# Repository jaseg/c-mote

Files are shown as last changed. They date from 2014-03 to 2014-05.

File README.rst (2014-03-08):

c-mote
======

Mote_ is hipster slang for small, low-power, long-lifetime sensor nodes. We want to build a sensor network consisting of about 40 motes at c-base and AfRA (both hackerspaces in Berlin). Traditionally, the term applies to wireless sensors, but since we already have enough rays bouncing around at both places we opted for less expensive, more reliable wired communication via RS-485_ instead.

Hardware
--------

We are planning the base board to be about 5*5cm. The heart of the system is an Atmel ATmega8_ microcontroller. Most of the components on the board will be surface-mounted, though we aim to not use anything smaller than 0805 packages so we can still solder it by hand. The board is supplied via 5V routed with the RS-485 bus.

All of the sensors are optional to allow greater flexibility.

Some of the unused microcontroller IOs are routed to a 2*5 pin male 2.54mm pin header which serves as a connector for daughter boards. The first planned daughter board is a frontend for diffuse IR telemetry.

Sensor auto-detection
~~~~~~~~~~~~~~~~~~~~~

The default firmware will include modules for all sensors. The available sensors will be probed on power-on. The following table summarizes the conditions under which each of the sensors will be considered absent.

==================  ==============================  ======================================================
Sensor              Considered absent, when...      Activate µC's internal pull-up for presence detection?
==================  ==============================  ======================================================
Analog temperature  U_in > 4.0V                     yes
Light               U_in > 4.0V                     yes
Oxygen              U_in > 4.0V                     yes
Sound               U_in > 4.0V                     yes
Methane             U_in > 4.0V                     yes
Barometer           Probing via I2C fails
Hygrometer          No response on bus
NRF24L01            Probing via SPI fails
Motion              See text below
==================  ==============================  ======================================================

The motion sensor's presence detection is a bit tricky. This sensor is considered absent when the input is a logical 0 and switches to a logical 1 after the µC's internal pull-up is activated. This procedure is using the fact that the AVR's internal pull-up is something below 50kΩ and the motion sensor's output impedance is something below 10kΩ. When the motion sensor is left unpopulated, a 200kΩ pull-down resistor is added instead.

Bus
---
Most likely we will end up using regular CAT5e or better ethernet cable since that stuff is cheap and will probably do the job. Contrary to what one might expect after having a glance on the standard, RS-485 (TIA-485-A) actually is kind of picky concerning bus topologies. We plan on routing a long chain, avoiding any branches, by using two of the ethernet cable's twisted pairs for both directions into dead ends if necessary.

Protocol
--------

The first iteration of the network will be based on cerebrum_, since basically everything we need is already implemented there. This network will consist of one dedicated, internet-connected bus master (some kind of linux system with an USB/RS-485 converter) running a cerebrum daemon collecting data and forwarding it to MQTT_ and Graphite_.

The medium-term goal is to get the next-gen cerebrum protocol to work which is completely distributed and directly compatible to 6LoWPAN_. At this point, it would be sensible to implement MQTT_ directly on the motes using contiki_ for its 6LoWPAN stack.

MAC address handling
~~~~~~~~~~~~~~~~~~~~
Cerebrum, and probably any successor to it, uses random 64-bit MAC adresses for auto-discovery. The current plan is to use a common firmware binary with sensor auto-detection on all nodes. Device-specific configuration, specifically device name, MAC and spatial coordinates should simply be stored in EEPROM. The chosen approach is to have all devices start with a build-specific, random MAC that is used until a proper, random MAC has been configured along with the device's name and coordinates. Thus, the devices can be added to the bus and configured one-by-one without requiring another compilation step.

.. _Mote:       https://en.wikipedia.org/wiki/Motes
.. _RS-485:     https://en.wikipedia.org/wiki/RS-485
.. _ATmega8:    http://www.atmel.com/Images/Atmel-2486-8-bit-AVR-microcontroller-ATmega8_L_summary.pdf
.. _cerebrum:   https://github.com/jaseg/cerebrum
.. _MQTT:       https://en.wikipedia.org/wiki/MQ_Telemetry_Transport
.. _Graphite:   https://github.com/graphite-project/graphite-web
.. _6LoWPAN:    https://en.wikipedia.org/wiki/6LoWPAN
.. _contiki:    http://www.contiki-os.org/

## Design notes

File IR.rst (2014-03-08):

IR Telemetry
============

The purpose of this board is to serve as an analog frontend for low-bitrate (≤1Mbps), short-range (≤5m) IR communication. The design consists of two identical halves which are supposed to cover on hemisphere each.

Transmission path
-----------------

Reception path
--------------
http://www.aliexpress.com/item/940nm-narrow-band-pass-filter-board-lens-filters-filter-diameter-8-0mm-night-vision-filter/569348422.html

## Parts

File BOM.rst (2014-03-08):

BOM
===

**Note:** In the following table, the brutto prices two conrad parts have been converted to USD for summation convenience.

==  ==============================================================  ==================================================  =========
#   What                                                            Sources                                             Price/ea.
==  ==============================================================  ==================================================  =========
1   RS485 driver SN75176BP                                          `Tayda <tayda1_>`__                                     0.39$
1   ATMega8 8-bit µC w/ nice peripheral selection and 5V operation  `Tayda <tayda2_>`__                                     1.89$
1   Crystal for good bus timing                                     `Tayda <tayda3_>`__                                     0.10$
1   Load caps for crystal oscillator, 22pF 0805 cer.                `Tayda <tayda4_>`__                                     0.01$
1   Buffer cap for entire circuit, 4.7µ electrolytic 2.54mm leads   `Tayda <tayda11_>`__                                    0.02$
1   4pin terminal for bus/VCC connection                            `Conrad <conrad1_>`__                                   0.73$
1   5pin terminal for contact connection (GND/VCC/IO1-3)            `Conrad <conrad2_>`__                                   0.91$
1   PCB <5*5cm                                                      `Seeedstudio <seeed1_>`__                               1.00$
1   LDO 3.3V SOT223 TS1117                                          `Reichelt <reich1_>`__ `Aliexpress <aliex16_>`__        0.06$
\   **Total**                                                                                                               5.05$
==  ==============================================================  ==================================================  =========

.. _tayda1:  http://www.taydaelectronics.com/ic-integrated-circuits/rs422-rs423-rs485/sn75176-sn75176bp-75176-buffers-line-drivers-ic.html
.. _tayda2:  http://www.taydaelectronics.com/ic-integrated-circuits/microcontrollers/atmel-atmega8-16au-tqfp-32-avr-8-bit-microcontroller-ic.html
.. _tayda3:  http://www.taydaelectronics.com/crystals-resonators-oscilliators/crystals/16-000-mhz-16-mhz-crystal-hc-49-s-low-profile.html
.. _tayda4:  http://www.taydaelectronics.com/capacitors/smd-ceramic-chip-capacitors/0805/22pf-50v-smd-ceramic-chip-capacitor.html
.. _tayda10: http://www.taydaelectronics.com/resistors/smd-chip-resistors/0805/50-x-smd-chip-resistors-10k-ohm-1-8w-1-0805.html
.. _tayda11: http://www.taydaelectronics.com/capacitors/electrolytic-capacitors/4-7uf-16v-105c-radial-electrolytic-capacitor-5x11mm.html
.. _conrad1: http://www.conrad.de/ce/de/product/567658/Loetbare-Schraubklemme-mit-Liftprinzip-AKZ692-V-Rastermass-254-mm-Polzahl-4-Gruen-50692040021E-Inhalt-1-St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
.. _conrad2: http://www.conrad.de/ce/de/product/567698/Loetbare-Schraubklemme-mit-Liftprinzip-AKZ692-V-Rastermass-254-mm-Polzahl-5-Gruen-50692050021E-Inhalt-1-St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
.. _seeed1:  http://www.seeedstudio.com/service/index.php?r=site/pcbService
.. _reich1:  https://secure.reichelt.de/TS-1117-BCW33/3/index.html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
.. _aliex16: http://www.aliexpress.com/item/Free-Shipping-100PCS-Original-AMS1117-3-3-AMS1117-3-3V-AMS1117-1117-3-3V-1A-Voltage/1149210196.html

Remember to also throw in a couple of **termination resistors** for the system in accordance to your cable's impedance (e.g. 100Ω for ethernet cable).

Indicator option 1: RGB LED
---------------------------

==  ==============================================================  ======================================  =========
#   What                                                            Sources                                 Price/ea.
==  ==============================================================  ======================================  =========
1   RGB LED as status indicator                                     `Tayda <tayda5_>`__                         0.27$
1   Cur. limit resistor for RGB LED, 0805, 150Ω (R)                 `Tayda <tayda12_>`__                        0.01$
2   Cur. limit resistor for RGB LED, 0805, 100Ω (G/B)               `Tayda <tayda13_>`__                        0.01$
\   **Total**                                                                                                   0.30$
==  ==============================================================  ======================================  =========

.. _tayda5:  http://www.taydaelectronics.com/leds/round-leds/5mm-leds/rgb-leds/rgb-led-5mm-common-cathode.html
.. _tayda12: http://www.taydaelectronics.com/resistors/smd-chip-resistors/0805/50-x-smd-chip-resistors-100-ohm-1-8w-1-0805.html 
.. _tayda13: http://www.taydaelectronics.com/resistors/smd-chip-resistors/0805/50-x-smd-chip-resistors-150-ohm-1-8w-1-0805.html

Indicator option 2: Red 8*8 LED dot matrix (32*32mm)
----------------------------------------------------

==  ==============================================================  ======================================  =========
#   What                                                            Sources                                 Price/ea.
==  ==============================================================  ======================================  =========
1   Red 8*8 32*32mm LED dot matrix                                  `Tayda <tayda14_>`__                        1.35$
1   7-ch NPN darlington array ULN2003APG                            `Tayda <tayda15_>`__                        0.28$
2   8bit shift register w/ output latches                           `Tayda <tayda16_>`__                        0.27$
1   NPN darlington transistor 2N5306                                `Tayda <tayda17_>`__                        0.14$
1   Transistor base resistor 0805 330K                              `Tayda <tayda18_>`__                        0.01$
8   LED current limit resistors 0805 100Ω                           `Tayda <tayda19_>`__                        0.01$
0   Alternative high current shift register                         `Digikey <digikey1_>`__                     1.51$
\   **Total**                                                                                                   2.40$
==  ==============================================================  ======================================  =========

.. _tayda14:  http://www.taydaelectronics.com/led-displays/dot-matrix/8x8-dot-matrix-led-display-red-3mm-common-cathode.html
.. _tayda15:  http://www.taydaelectronics.com/ic-integrated-circuits/transistor-arrays/uln2003apg-uln2003-array-7-npn-darlingtons-ic.html
.. _tayda16:  http://www.taydaelectronics.com/ic-integrated-circuits/74-series/74hc-series/74hc595-8-bit-shift-register-ic.html
.. _tayda17:  http://www.taydaelectronics.com/t-transistors/2n-series/2n5306-npn-darlington-transistor.html
.. _tayda18:  http://www.taydaelectronics.com/resistors/smd-chip-resistors/0805/50-x-smd-chip-resistors-330k-ohm-1-8w-1-0805.html
.. _tayda19:  http://www.taydaelectronics.com/resistors/smd-chip-resistors/0805/50-x-smd-chip-resistors-100-ohm-1-8w-1-0805.html
.. _digikey1: http://www.digikey.com/product-search/en?x=0&y=0&lang=en&site=us&KeyWords=TPIC6B595

Sensors
-------

======  ==============================================================  ==================================================  =========
#       What                                                            Sources                                             Price/ea.
======  ==============================================================  ==================================================  =========
1       Photoresistor                                                   `Tayda <tayda6_>`__                                     0.24$
1       Bootstrap resistor for photo resistor, 10k 0805                 `Tayda <tayda10_>`__                                    0.01$
0       Digital temperature sensor                                      `Tayda <tayda7_>`__                                     1.75$
0.5     Alternative analog temperature sensor LM335                     `Tayda <tayda20_>`__                                    0.81$
0.5     Alternative analog temperature sensor bias resistor                                                                     0.01$
1       PIR (motion sensor) module                                      `Aliexpress <aliex1_>`__ `(Proto) <aliex7_>`__          1.01$
0.3333  Optical particle sensor Sharp GP2Y1010AU0F w/ cable             `Aliexpress <aliex2_>`__ `(Proto) <aliex8_>`__          6.40$
0       Oxygen sensor Alphasense O2-A2 (1~2yr lifetime)                 `Aliexpress <aliex3_>`__                               51.84$
0.3333  Oxygen sensor Envitec OOA101-1 (compatible; 3yr lifetime)       `Aliexpress <aliex4_>`__ `(Proto) <aliex9_>`__          7.07$
0.3333  Passives for oxygen sensor                                                                                              0.05$
0.3333  3.5mm headphone plug for oxygen sensor                          `Tayda <tayda21_>`__                                    0.16$
0.5     Humidity sensor DHT22 (**replaces temp. sensor**)               `Aliexpress <aliex5_>`__ `(Proto) <aliex10_>`__         3.95$
1       Air pressure sensor BMP085                                      `Aliexpress <aliex6_>`__ `(Proto) <aliex11_>`__         2.19$
1       NRF24L01 (2.4GHz transceiver as used in r0kets)                 `Aliexpress <aliex12_>`__                               0.85$
0.3333  MQ214 Methane/Propane/Buthane sensor                            `Aliexpress <aliex13_>`__                               3.69$
0.3333  MQ214 load resistor 0805 43Ω                                    `Tayda <tayda22_>`__                                    0.01$
0       Piezo transducer                                                `Aliexpress <aliex14_>`__                               1.27$
0       3.5mm mono headphone jack for piezo transducer                                                                          0.20$
0       27mm piezo buzzer disc as force/vibration sensor                `Aliexpress <aliex15_>`__                               0.16$
\       **Total**                                                                                                              12.66$
======  ==============================================================  ==================================================  =========

.. _tayda6:  http://www.taydaelectronics.com/sensors-transducer/optical-sensor/photo-conductive-cell-resistor-ldr-650nm-radial-ke-10720.html 
.. _tayda7:  http://www.taydaelectronics.com/ic-integrated-circuits/temperature-sensors/ds18b20-1-wire-digital-temperature-sensor-ic-dallas.html
.. _tayda20: http://www.taydaelectronics.com/ic-integrated-circuits/temperature-sensors/lm335-precision-temperature-sensor-40c-to-100c-ic.html
.. _tayda21: http://www.taydaelectronics.com/3-5mm-stereo-plug.html
.. _tayda22: http://www.taydaelectronics.com/resistors/smd-chip-resistors/0805/50-x-smd-chip-resistors-43-ohm-1-8w-1-0805.html
.. _aliex1:  http://www.aliexpress.com/item/Free-Shipping-HC-SR501-Adjust-Infrared-IR-Pyroelectric-Infrared-PIR-module-Motion-Sensor-Detector-Module-We/1564561530.html
.. _aliex2:  http://www.aliexpress.com/item/2pcs-lot-GP2Y1010AU0F-100-NEW-SHARP-Optical-Dust-Sensor-GP2Y1010-free-shipping-add-cable/1670003835.html
.. _aliex3:  http://www.aliexpress.com/item/UK-Alphasense-alpha-O2-A2-oxygen-sensor-O2-A2/1613147048.html
.. _aliex4:  http://www.aliexpress.com/item/Envitec-oxygen-battery-oxygen-probe-ooa101-ooa101-1/1000408054.html
.. _aliex5:  http://www.aliexpress.com/item/10PCS-LOT-DHT22-AM2302-Digital-Temperature-and-Humidity-Sensor-DHT22-Free-shiping/1514942254.html
.. _aliex6:  http://www.aliexpress.com/item/Free-Shipping-10pcs-New-BMP085-Digital-Pressure-Sensor-module/1640086463.html
.. _aliex7:  http://www.aliexpress.com/item/NEW-PIR-Sensor-Human-Body-detecting-module-Pyroelectric-HC-SR501-For-Arduino-MCU-Freeshipping/875391018.html
.. _aliex8:  http://www.aliexpress.com/item/GP2Y1010AU0F-Compact-Optical-Dust-Sensor-Smoke-Particle-Sensor-With-Cable/1482509805.html
.. _aliex9:  http://www.aliexpress.com/item/Hot-4-Wire-Universal-Oxygen-Sensor-Lambda-Sensor-Free-Shipping-0258986501/1464938927.html
.. _aliex10: http://www.aliexpress.com/item/2pcs-DHT22-AM2302-SHT11-SHT15-Digital-Temperature-and-Humidity-Sensor-for-Ardunio-AVR-PIC-ARM-Raspberry/1628174960.html
.. _aliex11: http://www.aliexpress.com/item/5PCS-LOT-GY-65-BMP085-Atmospheric-Pressure-Altimeter-Module-Free-Shipping/1540253073.html
.. _aliex12: http://www.aliexpress.com/item/NRF24L01-wireless-data-transmission-module-2-4G-the-NRF24L01-20PCS-LOT-upgrade-version/603760995.html
.. _aliex13: http://www.aliexpress.com/item/Mq214-methane-sensor/1398325808.html
.. _aliex14: http://www.aliexpress.com/item/FREE-SHIPPING-30-Sensitive-New-Piezo-Under-saddle-Pickup-Transducer-Tuner-For-Ukulele/1402166893.html
.. _aliex15: http://www.aliexpress.com/item/20pcs-27mm-Thickness-0-33mm-Piezo-Disc-for-Buzzer-Pressure-Sensor-Speaker-DIY/1371976951.html

Loudness sensor subsystem
-------------------------
**Note:** The Op-Amp used in this subsystem is a dual type, so we need only one half of it. The other half is available for other uses.
Loudness sensor? → Microphone+amp+envelope detector

==  ==============================================================  ======================================  =========
#   What                                                            Sources                                 Price/ea.
==  ==============================================================  ======================================  =========
1   Electret microphone                                             `Tayda <tayda8_>`__                         0.25$
1   Dual Op-Amp                                                     `Tayda <tayda9_>`__                         0.11$
\*  Passives (**TODO**)                                                                                         0.05$
\   **Total**                                                                                                   0.41$
==  ==============================================================  ======================================  =========

.. _tayda8:  http://www.taydaelectronics.com/microphones/condenser-microphone-2-2k-ohm-1-5v.html
.. _tayda9:  http://www.taydaelectronics.com/ic-integrated-circuits/audio-amplifier-instrumentation-op-amp/tjm4558-dual-operational-amplifier-wide-band-soic-8-tjm4558cdt.html

Cabling
-------
We will use regular shielded ethernet cable. We will need a bunch of `splice boxes`_ to wire up cables going into dead ends.

.. _`splice boxes`: http://www.amazon.de/Logilink-LogiLink-Junction-box-metallized/dp/B001UG98NI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

Grand total
-----------
19USD

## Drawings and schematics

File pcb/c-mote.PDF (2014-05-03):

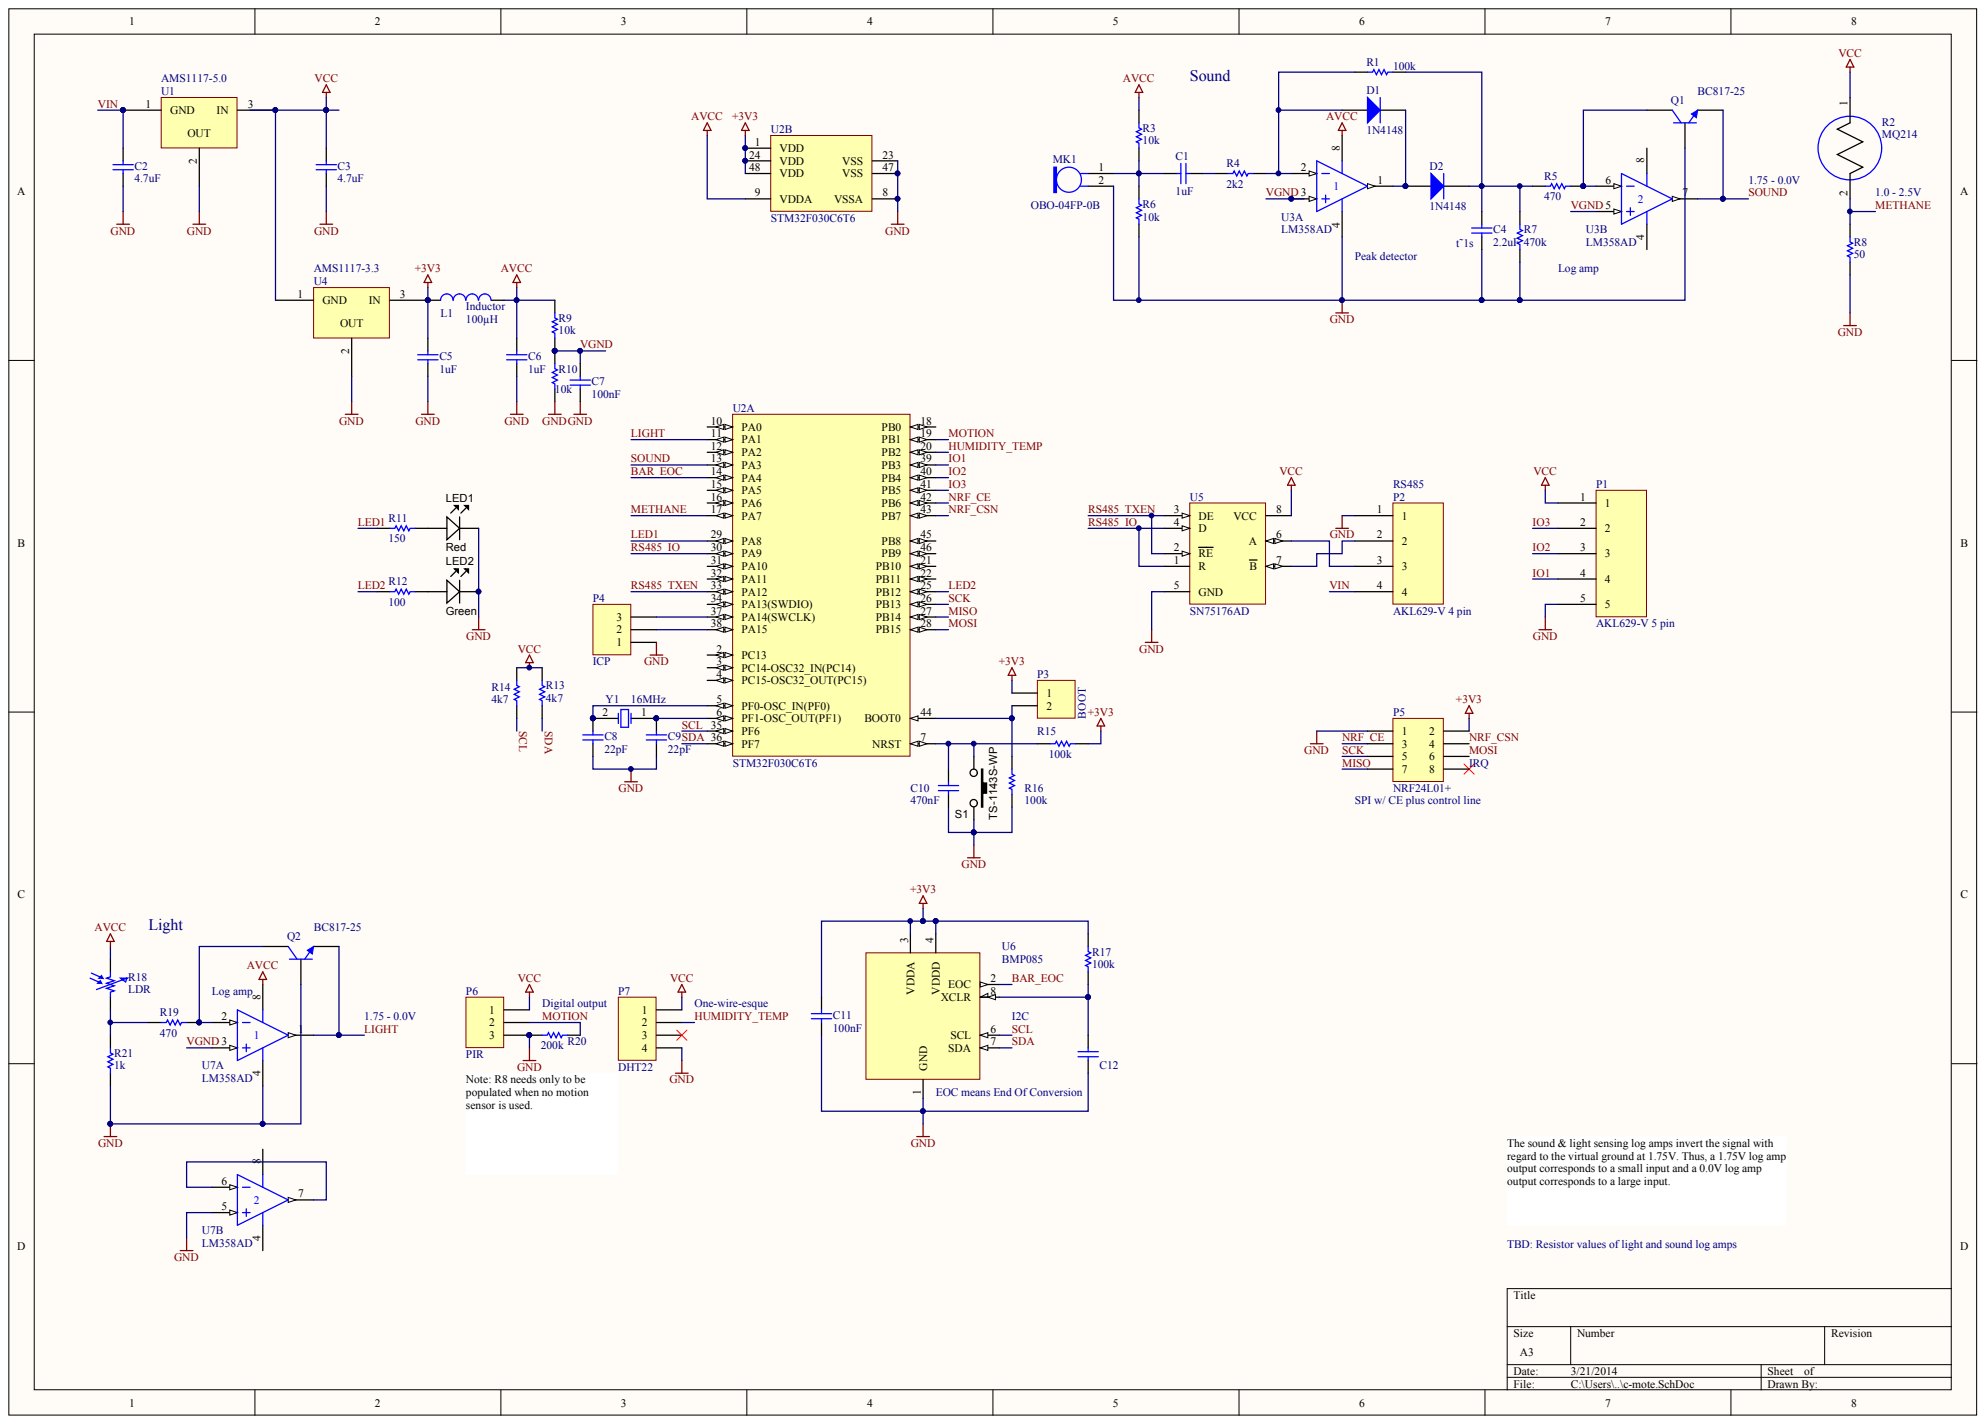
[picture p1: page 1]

SPI w/ CE plus control line

Note: R8 needs only to be
populated when no motion
sensor is used.

EOC means End Of Conversion

The sound & light sensing log amps invert the signal with
regard to the virtual ground at 1.75V. Thus, a 1.75V log amp
output corresponds to a small input and a 0.0V log amp
output corresponds to a large input.

TBD: Resistor values of light and sound log amps

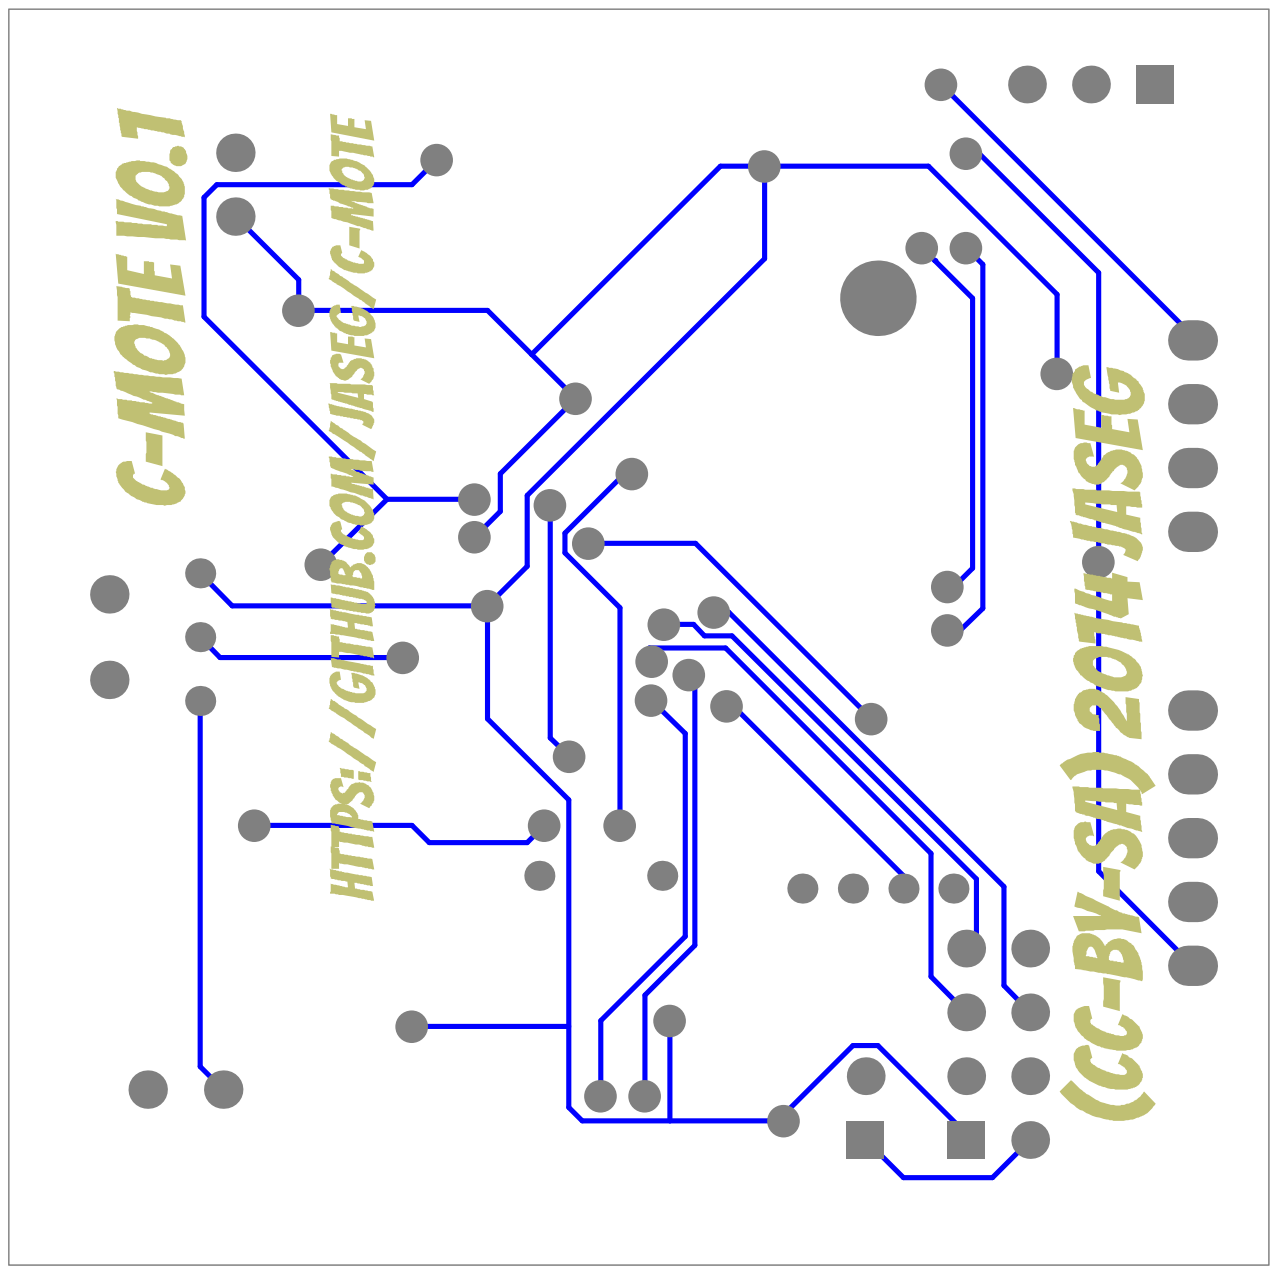
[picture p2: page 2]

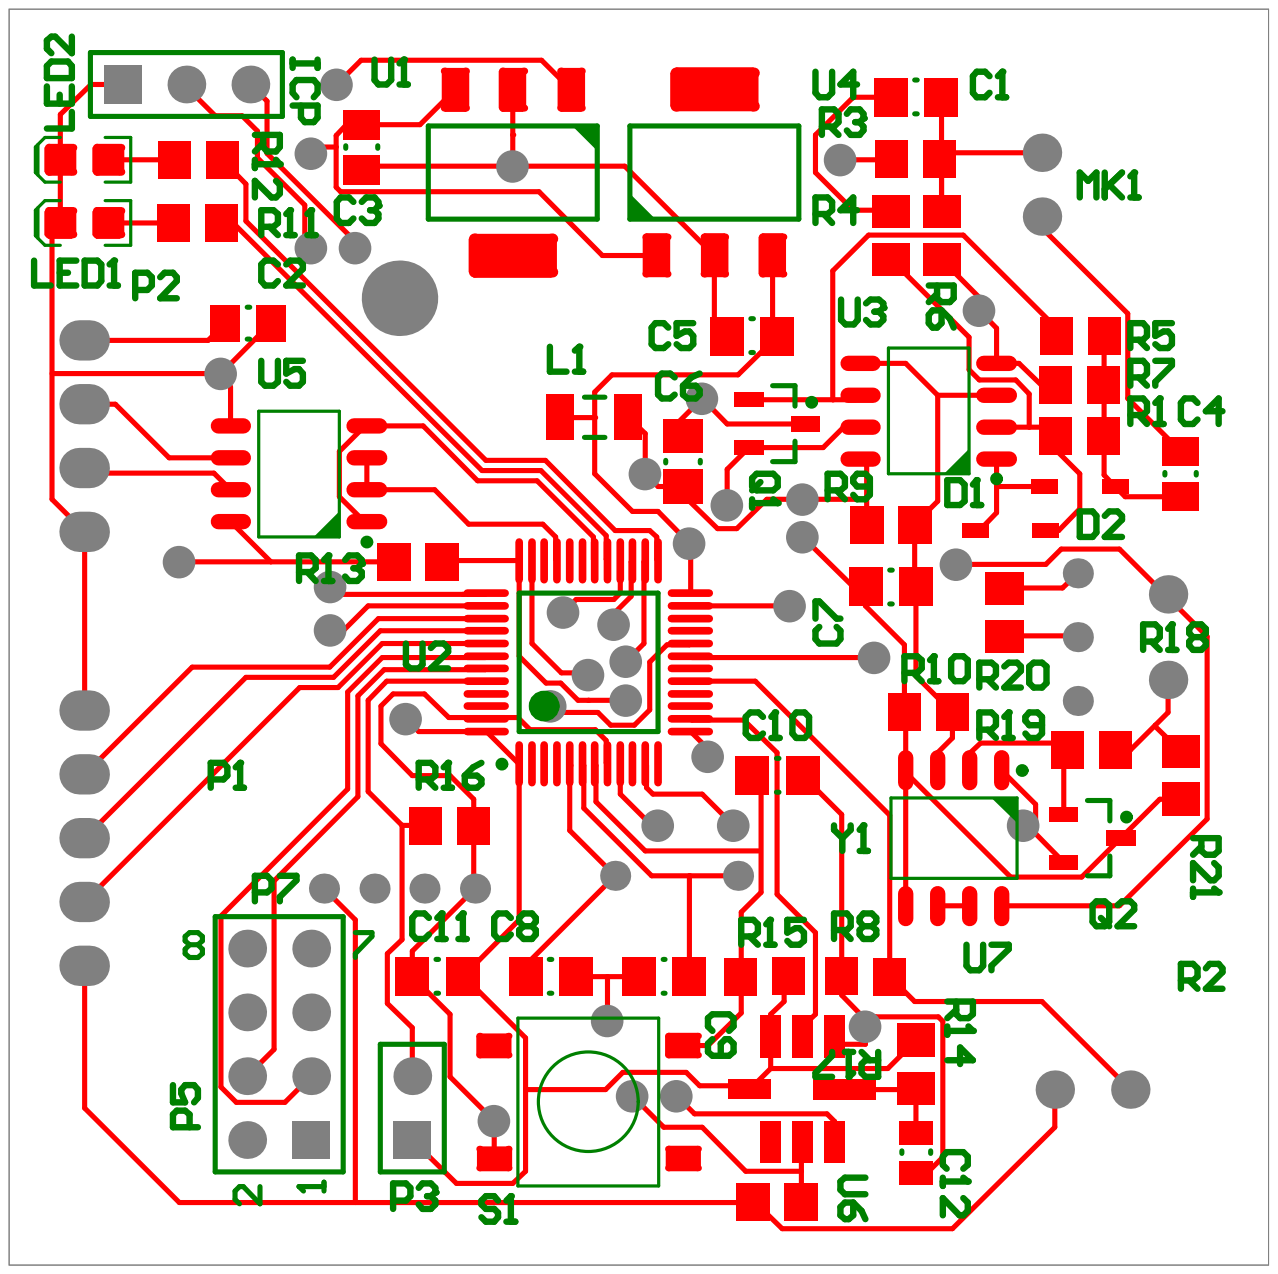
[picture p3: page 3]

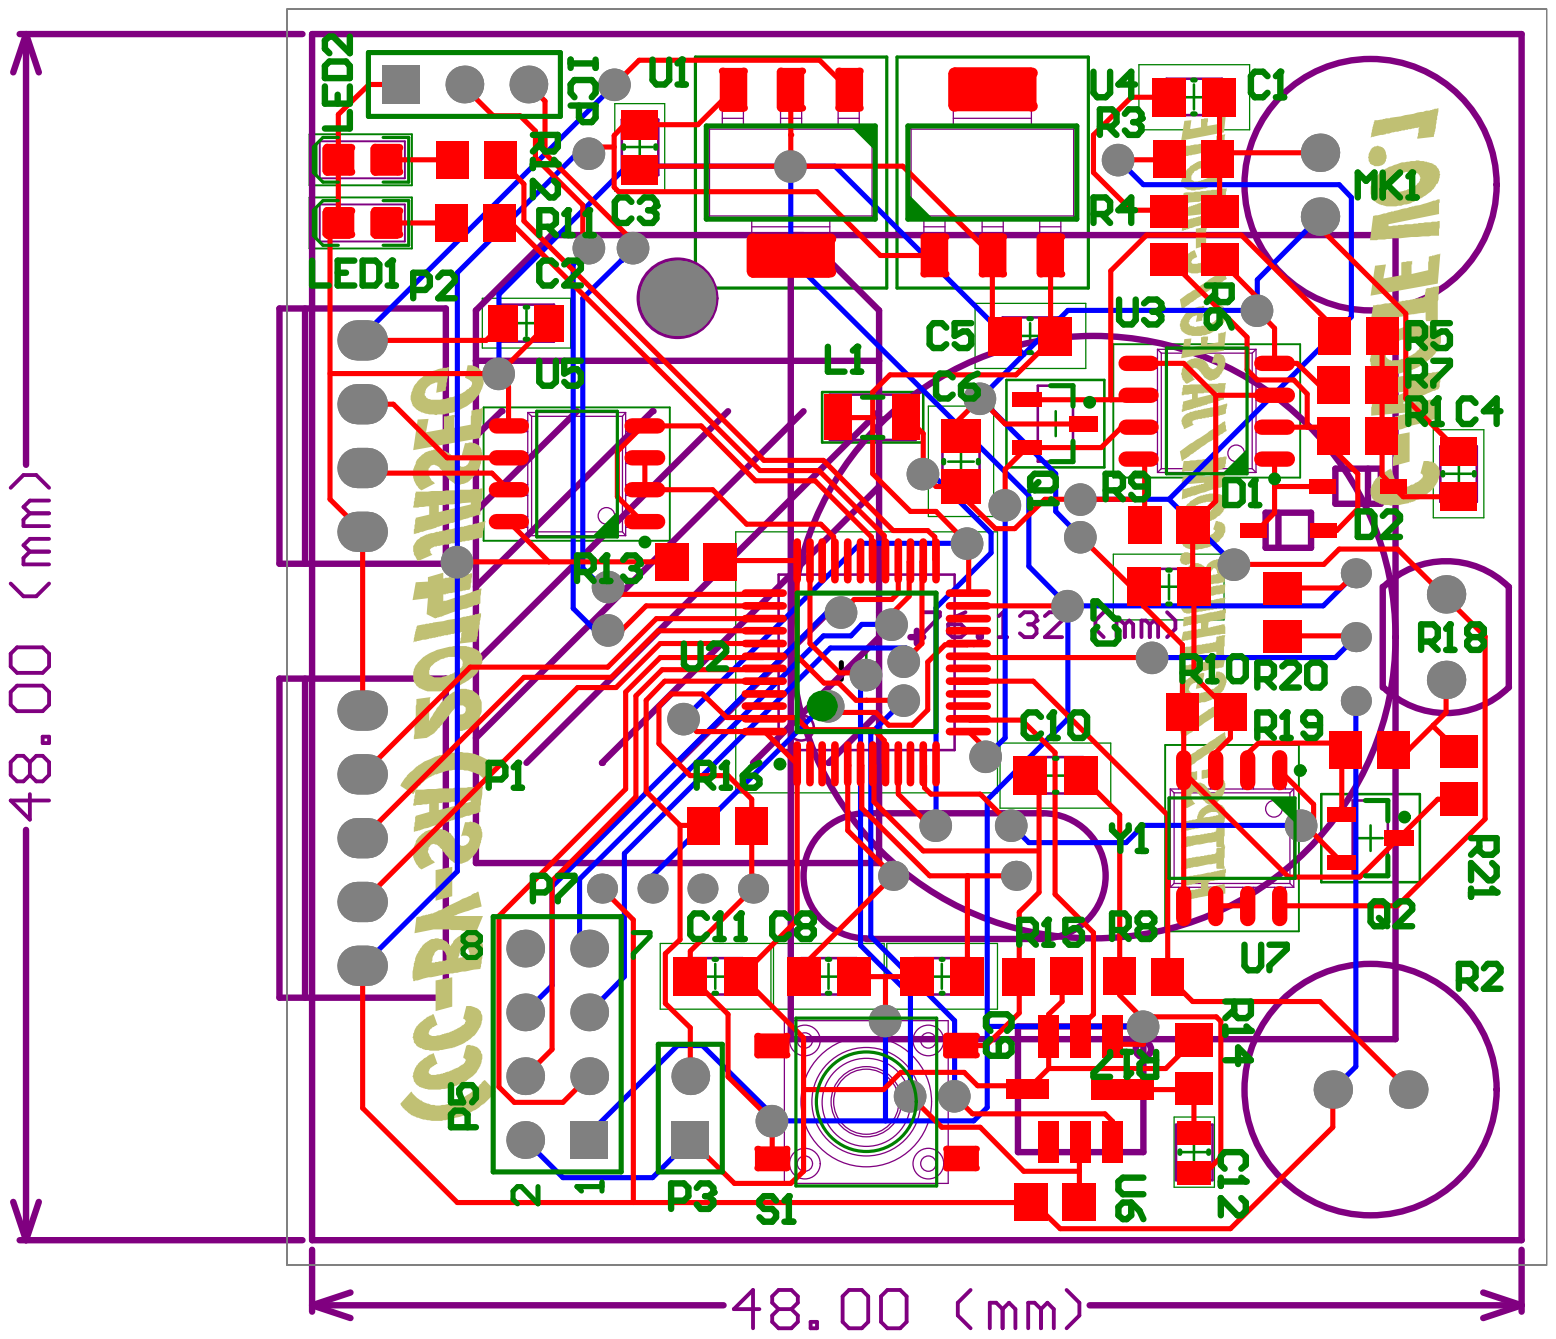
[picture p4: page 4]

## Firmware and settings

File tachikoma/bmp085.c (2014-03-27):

/*  Copyright (c) 2010  Christoph Mair <christoph.mair@gmail.com>
 *  Copyright (c) 2012  Bosch Sensortec GmbH
 *  Copyright (c) 2012  Unixphere AB
 *  Adapted for c-mote/tachikoma by Sebastian Götte
 *
 *  This driver supports the bmp085 and bmp18x digital barometric pressure
 *  and temperature sensors from Bosch Sensortec. The datasheets
 *  are available from their website:
 *  http://www.bosch-sensortec.com/content/language1/downloads/BST-BMP085-DS000-05.pdf
 *  http://www.bosch-sensortec.com/content/language1/downloads/BST-BMP180-DS000-07.pdf
 *
 *  A pressure measurement is issued by reading from pressure0_input.
 *  The return value ranges from 30000 to 110000 pascal with a resulution
 *  of 1 pascal (0.01 millibar) which enables measurements from 9000m above
 *  to 500m below sea level.
 *
 *  The temperature can be read from temp0_input. Values range from
 *  -400 to 850 representing the ambient temperature in degree celsius
 *  multiplied by 10.The resolution is 0.1 celsius.
 *
 *  Because ambient pressure is temperature dependent, a temperature
 *  measurement will be executed automatically even if the user is reading
 *  from pressure0_input. This happens if the last temperature measurement
 *  has been executed more then one second ago.
 *
 *  To decrease RMS noise from pressure measurements, the bmp085 can
 *  autonomously calculate the average of up to eight samples. This is
 *  set up by writing to the oversampling sysfs file. Accepted values
 *  are 0, 1, 2 and 3. 2^x when x is the value written to this file
 *  specifies the number of samples used to calculate the ambient pressure.
 *  RMS noise is specified with six pascal (without averaging) and decreases
 *  down to 3 pascal when using an oversampling setting of 3.
 *
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
 *  You should have received a copy of the GNU General Public License
 *  along with this program; if not, write to the Free Software
 *  Foundation, Inc., 675 Mass Ave, Cambridge, MA 02139, USA.
 */

#include "bmp085.h"
#include "config.h"
#include <stint.h>
#include <errno.h>

#define u8  uint8_t
#define s8  int8_t
#define u16	uint16_t
#define s16 int16_t
#define u32 uint32_t
#define s32 int32_t

#define BMP085_CHIP_ID			0x55
#define BMP085_CALIBRATION_DATA_START	0xAA
#define BMP085_CALIBRATION_DATA_LENGTH	11	/* 16 bit values */
#define BMP085_CHIP_ID_REG		0xD0
#define BMP085_CTRL_REG			0xF4
#define BMP085_TEMP_MEASUREMENT		0x2E
#define BMP085_PRESSURE_MEASUREMENT	0x34
#define BMP085_CONVERSION_REGISTER_MSB	0xF6
#define BMP085_CONVERSION_REGISTER_LSB	0xF7
#define BMP085_CONVERSION_REGISTER_XLSB	0xF8
#define BMP085_TEMP_CONVERSION_TIME	5

struct bmp085_calibration_data {
	s16 AC1, AC2, AC3;
	u16 AC4, AC5, AC6;
	s16 B1, B2;
	s16 MB, MC, MD;
};

struct bmp085_data {
	struct	bmp085_calibration_data calibration;
	s32	b6; /* calculated temperature correction coefficient */
};

static s32 bmp085_read_calibration_data(struct bmp085_data *data)
{
	u16 tmp[BMP085_CALIBRATION_DATA_LENGTH];
	struct bmp085_calibration_data *cali = &(data->calibration);
	s32 status = i2c_bulk_read(BMP085_I2C, BMP085_CALIBRATION_DATA_START, (u8 *)tmp, BMP085_CALIBRATION_DATA_LENGTH*sizeof(u16));
	if (status < 0)
		return status;

	cali->AC1 = be16toh(tmp[0]);
	cali->AC2 = be16toh(tmp[1]);
	cali->AC3 = be16toh(tmp[2]);
	cali->AC4 = be16toh(tmp[3]);
	cali->AC5 = be16toh(tmp[4]);
	cali->AC6 = be16toh(tmp[5]);
	cali->B1  = be16toh(tmp[6]);
	cali->B2  = be16toh(tmp[7]);
	cali->MB  = be16toh(tmp[8]);
	cali->MC  = be16toh(tmp[9]);
	cali->MD  = be16toh(tmp[10]);
	return 0;
}

static s32 bmp085_update_raw_temperature(struct bmp085_data *data)
{
	u16 tmp;
	s32 status;

	status = i2c_bulk_write(BMP085_I2C, BMP085_CTRL_REG, &BMP085_TEMP_MEASUREMENT, 1);
	if(status < 0)
		goto error;
	/* FIXME: Add timeout of BMP085_TEMP_CONVERSION_TIME milliseconds */
	while(!BMP085_GPIO->IDR & (1<<BMP085_PIN));

	status = i2c_bulk_read(BMP085_I2C, BMP085_CONVERSION_REGISTER_MSB, &tmp, sizeof(tmp));
	if(status < 0)
		goto error;

	return betoh16(tmp);
error:
	return status;
}

static s32 bmp085_update_raw_pressure(struct bmp085_data *data)
{
	u32 tmp = 0;
	s32 status;

	status = i2c_bulk_write(BMP085_I2C, BMP085_CTRL_REG, BMP085_PRESSURE_MEASUREMENT+(BMP085_OVERSAMPLING<<6), 1);
	if(status < 0)
		goto error;

	/* FIXME add timeout of (2+(3 << BMP085_OVERSAMPLING)) milliseconds */
	while(!BMP085_GPIO->IDR & (1<<BMP085_PIN));

	/* copy data into a u32 (4 bytes), but skip the first byte. */
	status = i2c_bulk_read(BMP085_I2C, BMP085_CONVERSION_REGISTER_MSB, ((u8 *)&tmp)+1, 3);
	if(status < 0)
		goto error;

	return betoh32(tmp) >> (8-BMP085_OVERSAMPLING);;
error:
	return status;
}

/*
 * This function starts the temperature measurement and returns the value
 * in tenth of a degree celsius.
 */
static s32 bmp085_get_temperature(struct bmp085_data *data, int *temperature)
{
	struct bmp085_calibration_data *cali = &data->calibration;
	long x1, x2;
	int status;

	status = bmp085_update_raw_temperature(data);
	if (status < 0)
		goto exit;

	x1 = ((status - cali->AC6) * cali->AC5) >> 15;
	x2 = (cali->MC << 11) / (x1 + cali->MD);
	data->b6 = x1 + x2 - 4000;
	/* if NULL just update b6. Used for pressure only measurements */
	if (temperature != NULL)
		*temperature = (x1+x2+8) >> 4;

exit:
	return status;
}
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

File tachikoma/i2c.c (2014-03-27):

#include <i2c.h>

/* Note: We are not using ST's drivers here because they are kind of bloated. After all, we are getting along just find
 * with raw register accesses. */

void i2c_init(I2C_TypeDef *I2Cx){
	/* Force soft reset */
	I2Cx->CR1 = 0;
	I2Cx->CR1 = I2C_CR1_PE;
}

void i2c_disable(I2C_TypeDef *I2Cx){
	I2Cx->CR1 = 0;
}

int i2c_enabled(I2C_TypeDef *I2Cx){
	return !!(I2Cx->CR1&I2C_CR1_PE);
}

static int i2c_raw_write(I2C_TypeDef *I2Cx, uint8_t data){
	I2Cx->TXDR = data;
	while(!(I2Cx->ISR & I2C_FLAG_TXIS)); /* Wait for transfer */
	if(I2Cx->ISR & I2C_FLAG_NACKF) /* NACK received? */
		return -1;
	return 0;
}

static void i2c_raw_read(I2C_TypeDef *I2Cx, uint8_t *dst){
	while(!(I2Cx->ISR & I2C_FLAG_RXNE)); /* Wait for transfer */
	dst = I2Cx->RXDR;
}

int i2c_bulk_write(I2C_TypeDef *I2Cx, uint8_t device_addr, uint8_t reg, uint8_t *buf, size_t count){
	const uint8_t nbytes = 3;
    I2Cx->CR2 = I2C_CR2_AUTOEND | nbytes<<16 | I2C_CR2_START | device_addr;
	/* Now, the slave address is being transmitted. */
	while(!(I2Cx->ISR & I2C_FLAG_TXIS)); /* Wait for transfer */
	if(I2Cx->ISR & I2C_FLAG_NACKF) /* NACK received? */
		return -1;

	if(i2c_raw_write(ctx, reg))
		return -1;

	uint8_t *end = data+count;
	while(*data != end)
		if(i2c_raw_write(ctx, *data++))
			return -1;
	return 0;
}

int i2c_bulk_read(I2C_TypeDef *I2Cx, uint8_t device_addr, uint8_t reg, uint8_t *buf, size_t count){
	const uint8_t nbytes = 2;
    I2Cx->CR2 = I2C_CR2_AUTOEND | nbytes<<16 | I2C_CR2_START | device_addr;
	/* Now, the slave address is being transmitted. */
	while(!(I2Cx->ISR & I2C_FLAG_TXIS)); /* Wait for transfer */
	if(I2Cx->ISR & I2C_FLAG_NACKF) /* NACK received? */
		return -1;

	if(i2c_raw_write(ctx, reg))
		return -1;

    I2Cx->CR2 = I2C_CR2_AUTOEND | nbytes<<16 | I2C_CR2_WRN | I2C_CR2_START | device_addr;
	uint8_t *end = data+count;
	while(*data != end)
		i2c_raw_read(ctx, data++);

	return 0;
}

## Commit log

2014-02-24 Added html-rendered BOM for github
2014-02-24 BOM should be more or less complete now, now even with LED matrix
2014-02-25 Moar sensors. Also, moar doc (created a README).
2014-02-25 Fixed particle sensor link for missing cable
2014-02-25 Fixed a link in the BOM
2014-02-25 Added an air pressure sensor
2014-02-25 Added the IR comm daughter board header to the spec
2014-02-25 Added prototype quantity sensor links
2014-02-25 Added MQ214 air pressure sensor
2014-02-25 Specced MQ214 load resistor
2014-03-05 Schematics work in progress
    [c-mote.PrjPcb, c-mote.SchDoc]
2014-03-05 Added regulated power supply
    [auxcomp.SchLib, c-mote.PrjPcb, c-mote.SchDoc]
2014-03-05 Added oxygen sensor signal conditioning
    [auxcomp.SchLib, c-mote.PrjPcb, c-mote.SchDoc]
2014-03-05 Added sound loudness sensor
    [c-mote.SchDoc]
2014-03-05 Added more sensors (motion, digital humidity/temp, pressure)
    [auxcomp.SchLib, c-mote.SchDoc]
2014-03-05 Added PDF export of schematic
2014-03-06 Fixed light & temperature sensing. Added methane sensor
    [auxcomp.SchLib, c-mote.PrjPcb, c-mote.SchDoc]
2014-03-06 Added a comment on the log amp output characteristic
    [c-mote.PrjPcb, c-mote.SchDoc]
2014-03-08 Fixed I2C pull-ups and sensor auto-detection
    [c-mote.PrjPcb, c-mote.SchDoc]
2014-03-08 Added info on sensor auto-detection
2014-03-08 Fixed sensor detection table markup
2014-03-08 Use the AVR's internal reference voltage as VGND
    [c-mote.SchDoc]
2014-03-10 Now using an STM32F0 ARM Cortex M0 ...instead of an ATMega8
    [c-mote.PrjPcb, c-mote.SchDoc]
2014-03-10 Removed analog temperature and oxygen sensors
    [c-mote.SchDoc]
2014-03-10 Fixed analog voltages for new microcontroller
    [c-mote.SchDoc]
2014-03-10 Updated the RS485 interface
    [c-mote.PrjPcb]
2014-03-14 Slowly adding PCB footprints
    [auxcomp.PcbLib, c-mote.PcbDoc, c-mote.PrjPcb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]
2014-03-14 Added ALL the footprints
    [auxcomp.PcbLib, c-mote.PcbDoc, c-mote.SchDoc]
2014-03-14 PCB: Preliminary component positioning
    [auxcomp.PcbLib, c-mote.PcbDoc, c-mote.SchDoc]
2014-03-14 Further work on component positioning
    See also http://i.imgur.com/FjJIh98.png
    [c-mote.PcbDoc, c-mote.SchDoc]
2014-03-16 First complete component placement draft
    [auxcomp.PcbLib, auxcomp.SchLib, c-mote.PcbDoc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]
2014-03-16 Started experimental routing
    [auxcomp.PcbLib, c-mote.PcbDoc, c-mote.PrjPcb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]
2014-03-17 Continued routing
    [c-mote.PcbDoc, c-mote.SchDoc]
2014-03-17 Started routing the µC
    [auxcomp.PcbLib, c-mote.PcbDoc, c-mote.SchDoc]
2014-03-19 Continued routing, fixed SMD pads
    [auxcomp.PcbLib, c-mote.PcbDoc, c-mote.SchDoc]
2014-03-20 Routing almost complete
    [c-mote.PcbDoc, c-mote.SchDoc]
2014-03-20 First revision of the PCB layout finished
    [c-mote.PcbDoc, c-mote.SchDoc]
2014-03-20 Made a shiny PDF export.
    [c-mote.PrjPcb]
2014-03-21 Added a serial port for in-circuit-programming
    [c-mote.PcbDoc, c-mote.PrjPcb, c-mote.SchDoc]
2014-05-03 Housekeeping: moved PCB files into subdir
    [auxcomp.PcbLib, auxcomp.SchLib, c-mote.PcbDoc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]

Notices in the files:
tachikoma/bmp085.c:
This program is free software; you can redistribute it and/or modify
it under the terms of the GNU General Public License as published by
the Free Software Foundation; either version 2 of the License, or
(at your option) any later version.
